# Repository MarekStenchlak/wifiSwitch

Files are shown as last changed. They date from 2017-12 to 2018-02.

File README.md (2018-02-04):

# wifiSwitch

## MQTT wifi wall switch using ESP8266-01

### Description
Switch can be controlled via **MQTT** or **touch button.**

it is well suited for 68mm Europe wall boxes.

Switch is based on wifi board [ESP8266-01](https://en.wikipedia.org/wiki/ESP8266).

Code is implemented in Arduino. Source files can be found in repository.

**This project requires 220V mains to operate properly**

**If you are not familiar with mains DO NOT TRY TO INSTALL THIS SWITCH**

**Proceed only if you know what you are doing !!!**

Board can be ordered on OSH park:
  https://oshpark.com/shared_projects/9JxnbNwu

### Schematics
Schematics for this project was designed using Eagle.

Eagle project can be found in repository.

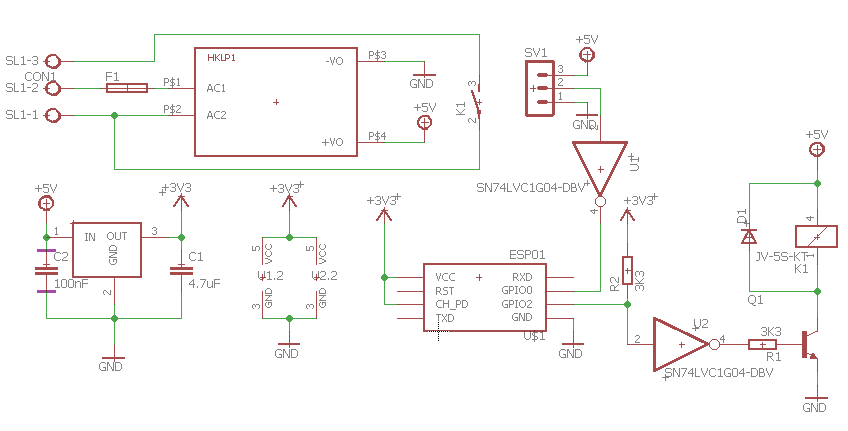
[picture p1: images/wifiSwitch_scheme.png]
Eagle Scheme Schematics


### Board

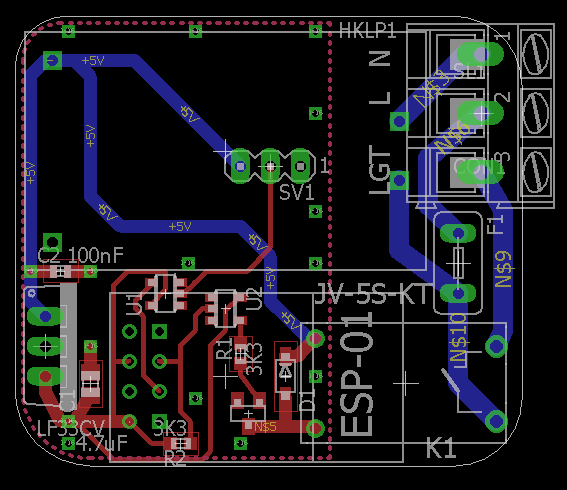
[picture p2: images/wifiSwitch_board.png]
Eagle Board Board


### BOM (Bill Of Materials)
*TODO*

### 3D model
3D model was designed in Sketch-Up and exported to STL files.

Model consists of 3 parts: **box, frame and button cover.**

3D model files and exported STL files can be found in repository.

Exploded view looks like this:

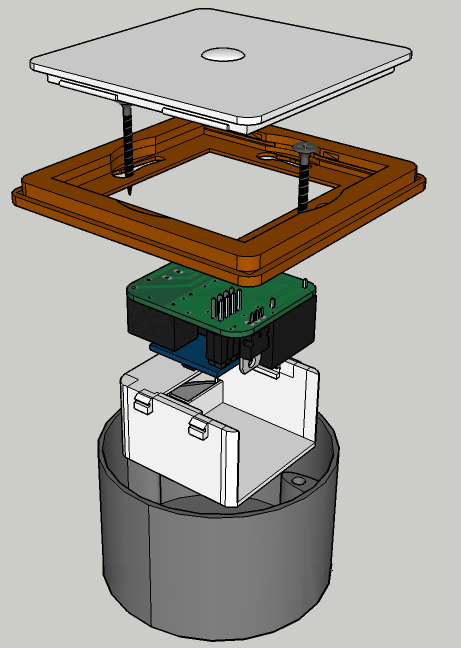
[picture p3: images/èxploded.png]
3D exploded view 3D exploded


## Setup

### Wiring
**Be sure you know what you are doing! Never touch any live wires ! Be sure to turn off electricity when dealing with mains!**

If you do not have **Neutral** wire in the wall box (which you probably don`t), you will have to wire new cable and connect it to **Neutral.**

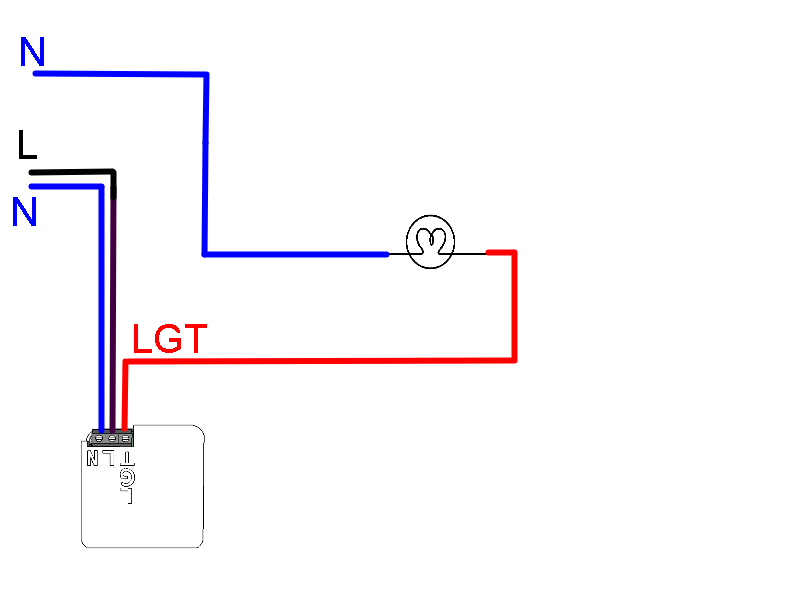
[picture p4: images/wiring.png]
wiring diagram


### MQTT broker
To use this switch you need to have an MQTT broker like [Mosquitto](https://mosquitto.org/) installed on a server or RaspeberryPi in your local wifi network.

To install Mosquitto, please follow this guide: [Setup mosquitto MQTT broker](https://www.digitalocean.com/community/tutorials/how-to-install-and-secure-the-mosquitto-mqtt-messaging-broker-on-ubuntu-16-04)

or this guie for RaspberryPi: [Setup mosquitto MQTT broker on RPi](http://www.instructables.com/id/Installing-MQTT-BrokerMosquitto-on-Raspberry-Pi/)

The bast practise is to set static IP address to the MQTT broker server or raspberryPi running mosquitto.

### WifiSwitch settings
This switch is using [WifiManager](https://github.com/tzapu/WiFiManager) project to set-up switch parameters.

When the switch is connected to mains, it tries to connect to configured Wifi network and MQTT broker. If it is not able to connect or is not configured, it enters the configuration mode.

#### Configuration mode
  When in configuration mode, the switch creates its own wifi network.
  This network`s SSID consists of string "ESP_HOME" followed by its MAC address 
  
  e.g: ESP_HOME A1:B2:3A:4E:2D:E2
    
  This network has no Password.
  
  After you connect to this network (e.g using smartphone) enter IP address 
  
  **192.168.4.1**
  
  Then configure:
  
  wifi SSID
  
  wifi Password
  
  MQTT broker IP (or DNS name)
  
  MQTT broker port
  
  MQTT username
  
  MQTT password
  
  MQTT topic
    
## Final Product

### Assembled board
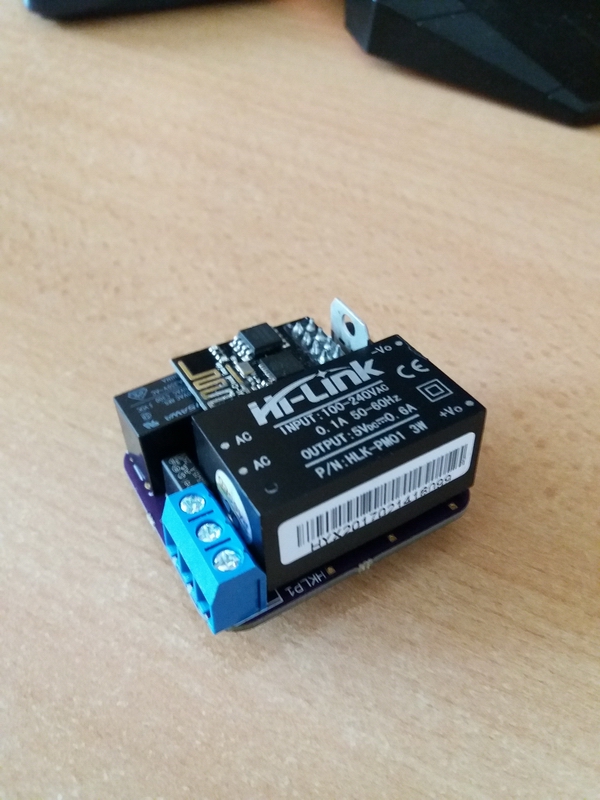
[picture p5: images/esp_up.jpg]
Assembled board 1 Assembled Board1


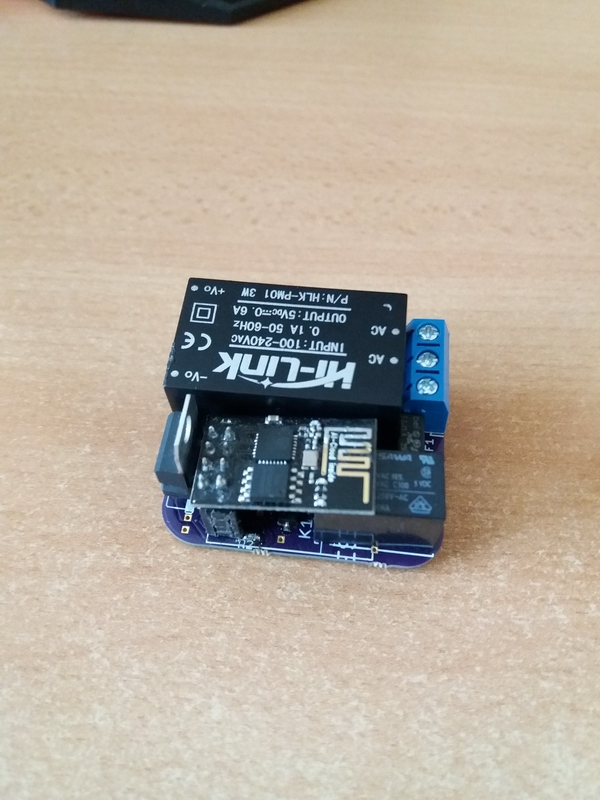
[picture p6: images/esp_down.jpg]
Assembled board 2 Assembled Board2


### Assembled switch

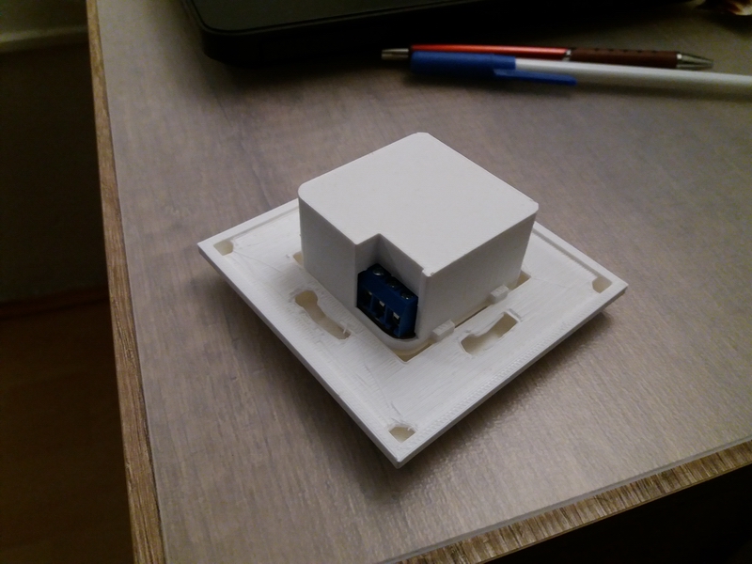
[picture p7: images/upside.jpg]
Assembled switch 1


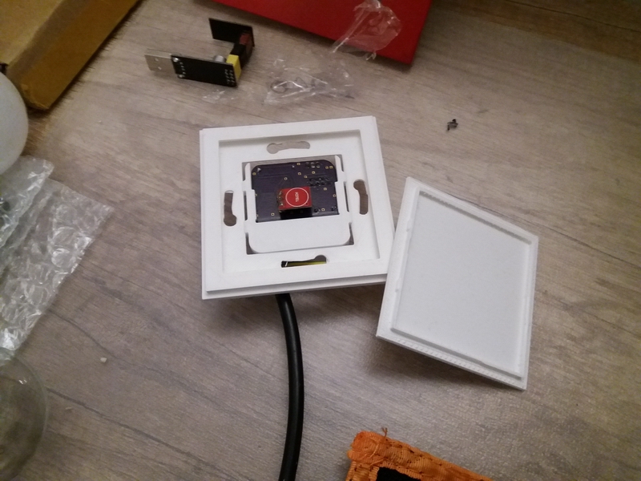
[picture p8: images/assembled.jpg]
Assembled switch 2


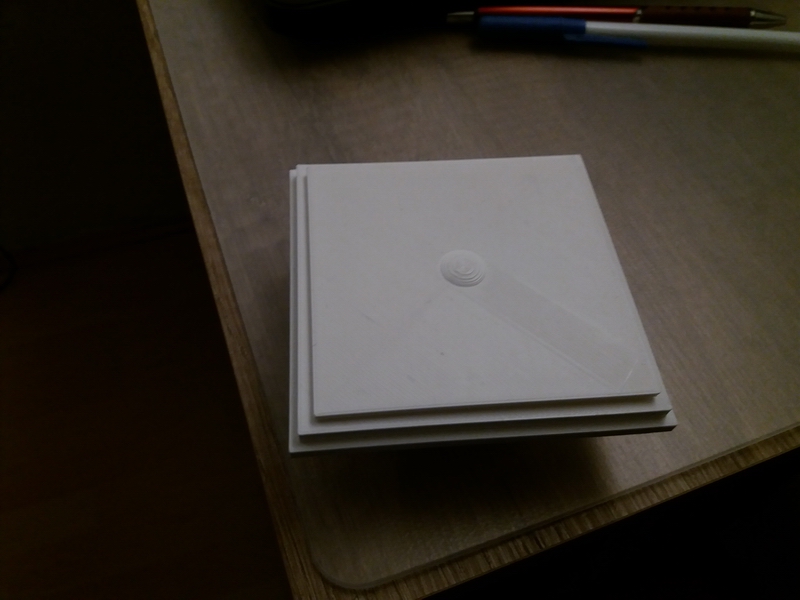
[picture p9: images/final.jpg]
Assembled switch 3


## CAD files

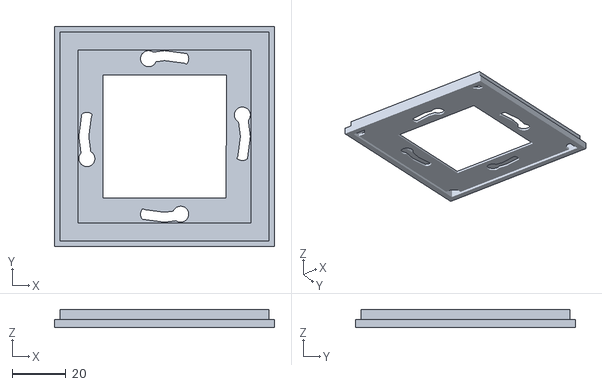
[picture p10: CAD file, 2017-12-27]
3d model/stl/frame.stl
81.7 x 81.7 x 6.77

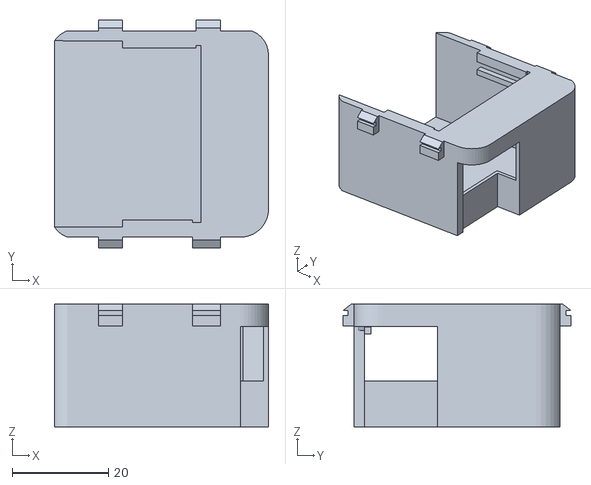
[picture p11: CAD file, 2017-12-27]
3d model/stl/box_rounded.stl
44.5 x 47.3 x 25.5

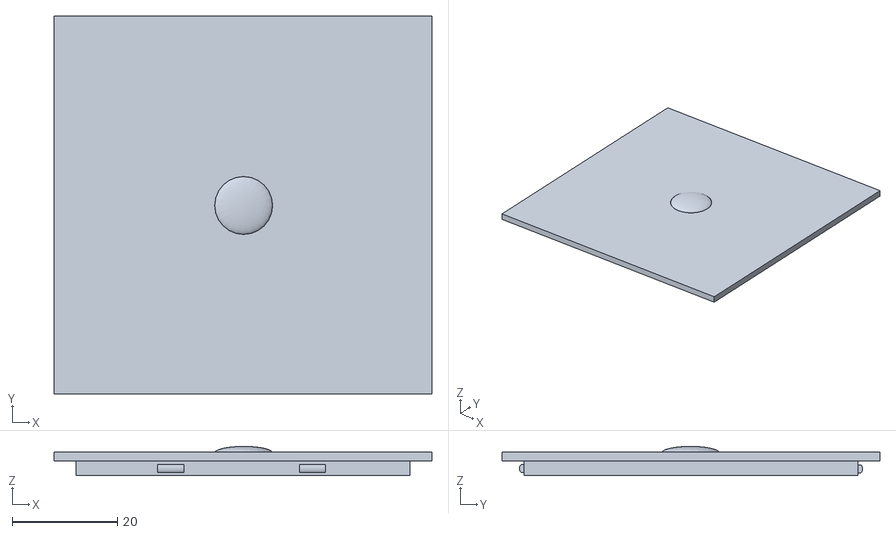
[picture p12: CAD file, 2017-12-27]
3d model/stl/button_flat.stl
71.7 x 71.7 x 5.55

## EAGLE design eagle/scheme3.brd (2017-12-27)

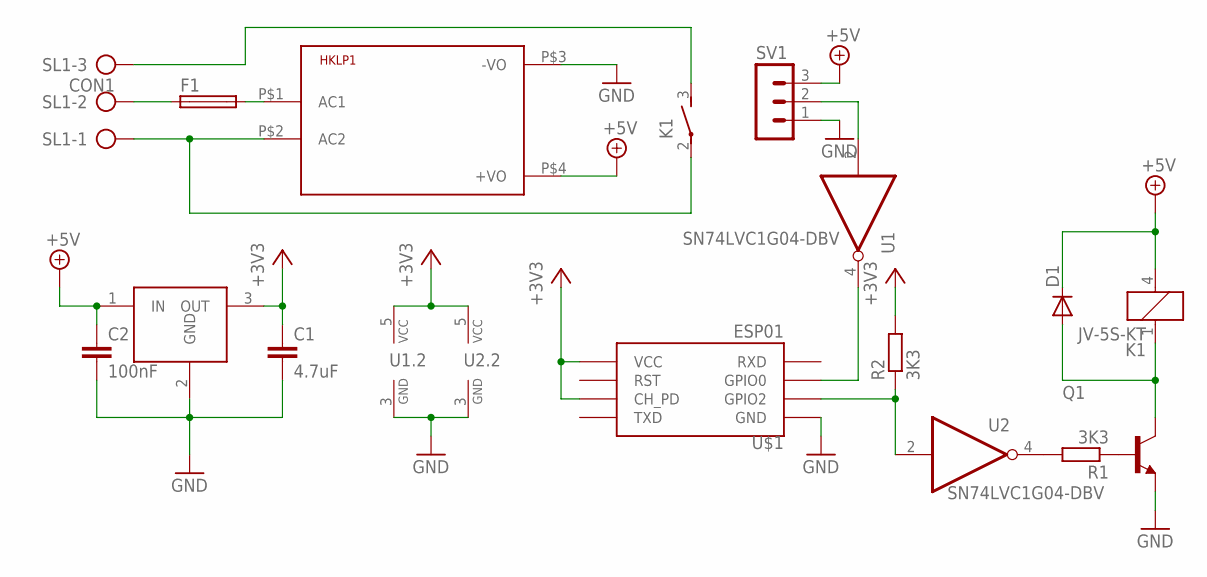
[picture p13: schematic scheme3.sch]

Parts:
C1: 4.7uF; C0805
C2: 100nF; C0603
D1: D-SOD123; SOD123
F1: TE5
HKLP1: HKLPM01
K1: JV-5S-KT; JV-KT
Q1: BC817-16-NPN-SOT23-BEC; SOT23-BEC
R1, R2: 3K3; R0603
SL1: CON1; AK300/3
SV1: MA03-1
U1, U2: SN74LVC1G04-DBV; SOT23-5
U$1: ESP01
U$2: LF33CV; TO220V

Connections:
+3V3: C1.1, R2.2, U1.5 (VCC), U2.5 (VCC), U$1.CH_PD, U$1.VCC, U$2.3 (OUT)
+5V: C2.1, D1.1 (C), HKLP1.P$4 (+VO), K1.4 (2), SV1.3, U$2.1 (IN)
GND: C1.2, C2.2, HKLP1.P$3 (-VO), Q1.E, SV1.1, U1.3 (GND), U2.3 (GND), U$1.GND, U$2.2 (GND)
unnamed: Q1.B, R1.1
unnamed: R2.1, U2.2 (A), U$1.GPIO2
unnamed: R1.2, U2.4 (Y)
unnamed: D1.2 (A), K1.1, Q1.C
unnamed: F1.1, SL1.2
unnamed: SV1.2, U1.2 (A)
unnamed: HKLP1.P$2 (AC2), K1.2, SL1.1
unnamed: K1.3 (S), SL1.3
unnamed: F1.2, HKLP1.P$1 (AC1)
unnamed: U1.4 (Y), U$1.GPIO0

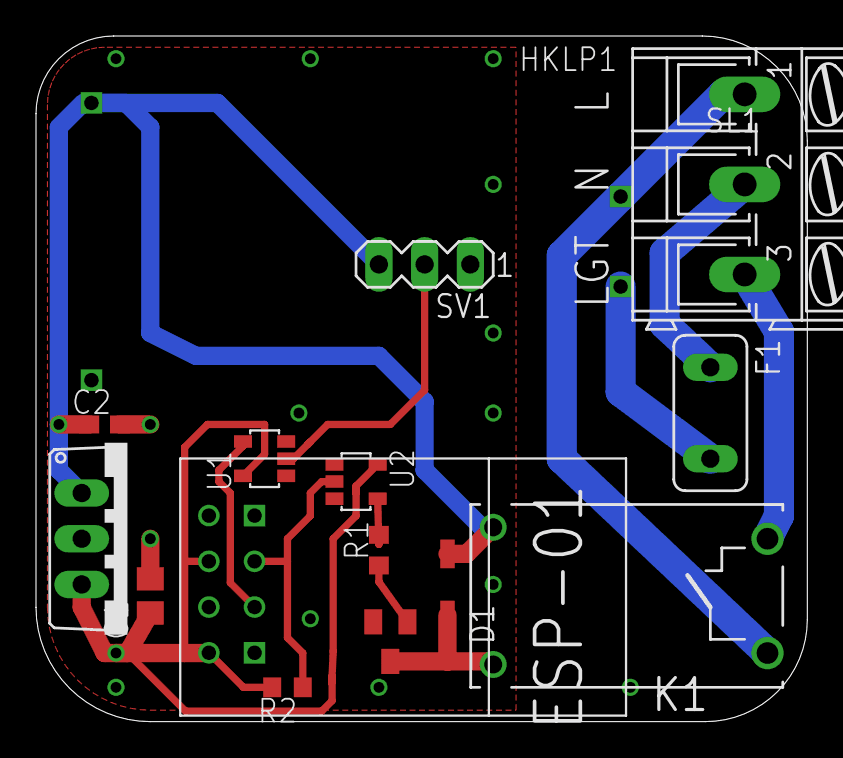
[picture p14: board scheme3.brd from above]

Board: 2 copper layers, 42.9 x 38.1 mm, 15 parts (0 on the bottom side), 13 nets.

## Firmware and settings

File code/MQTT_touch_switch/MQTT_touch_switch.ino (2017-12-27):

#include <FS.h>                   //this needs to be first, or it all crashes and burns...

#include <ESP8266WiFi.h>          //https://github.com/esp8266/Arduino
#include <DNSServer.h>
#include <ESP8266WebServer.h>
#include <WiFiManager.h>          //https://github.com/tzapu/WiFiManager
#include <ArduinoJson.h>          //https://github.com/bblanchon/ArduinoJson
#include <PubSubClient.h>         //https://github.com/knolleary/pubsubclient
#include "OneButton.h"            //https://github.com/mathertel/OneButton

#define BUTTON_PIN       0
#define RELAY_PIN       2
#define DISCOVERY_TOPIC "discovery"
#define STATE_SUFFIX "/state"
#define LONG_PRESS_RESET_VALUE 5 // time to reset ESP8266 to Configuration state in seconds

//flag for saving data
bool shouldSaveConfig = false;

//define your default values here, if there are different values in config.json, they are overwritten.
//char mqtt_server[40];
char mqtt_server[50];
char mqtt_port[6];
char mqtt_user[40];
char mqtt_pass[40];
char mqtt_topic[45];

volatile boolean relayStatus = true; // The logic is inverted, switch is opened on "1" .
volatile boolean isPublishStatus = false;

WiFiManager wifiManager;

WiFiClient espClient;
PubSubClient client(espClient);

OneButton button(BUTTON_PIN, true);

//callback notifying us of the need to save config
void saveConfigCallback () {
  Serial.println("Should save config");
  shouldSaveConfig = true;
}

// MQTT callback
void callback(char* topic, byte* payload, unsigned int length) {
  
  if (strcmp(topic, mqtt_topic) == 0){
    // Switch ON the relay if "1" was received as the first character on the topic
    if ((char)payload[0] == '1') {
      // inverse logic because of inverter in the circuit
      relayStatus = false;
    }  
    // Switch OFF the relay if "0" was received as the first character on the topic
    if ((char)payload[0] == '0') {
      // inverse logic because of inverter in the circuit
      relayStatus = true;
    }
    // Toggle the relay if "2" was received as the first character on the topic
    if ((char)payload[0] == '2') {
      relayStatus = !relayStatus;
    }
    // MQTT command to reset the ESP
    // Reset the ESP if "x" was received as the first character on the topic
    if ((char)payload[0] == 'x')
    {
      Serial.println("Reseting ESP...");
      //client.disconnect();
      runOnDemandSetup();
    }
    // debug output
    Serial.println(relayStatus);
    
    digitalWrite(RELAY_PIN, relayStatus);
    publishStatus(mqtt_topic);
  }
  
  if (strcmp(topic, DISCOVERY_TOPIC) == 0)
  {
    if ((char)payload[0] == '1') {
      publishStatus(mqtt_topic);
    }
  }
}

void setup() {
  // put your setup code here, to run once:
  //Serial.begin(115200);
  Serial.begin(115200,SERIAL_8N1,SERIAL_TX_ONLY);
  Serial.println();

  pinMode(RELAY_PIN, OUTPUT);
  digitalWrite(RELAY_PIN, relayStatus);

  // set Touch pin to input  > interupt
  pinMode(BUTTON_PIN, INPUT);
  
  button.attachClick(oneClickFunction);
  button.attachLongPressStart(longPressStart);
  button.attachLongPressStop(longPressStop);
  button.attachDuringLongPress(longPress);
  button.setPressTicks(LONG_PRESS_RESET_VALUE*1000);
  //clean FS for testing 
  //SPIFFS.format();

  //read configuration from FS json
  Serial.println("mounting FS...");

  if (SPIFFS.begin()) {
    Serial.println("mounted file system");
    if (SPIFFS.exists("/config.json")) {
      //file exists, reading and loading
      Serial.println("reading config file");
      File configFile = SPIFFS.open("/config.json", "r");
      if (configFile) {
        Serial.println("opened config file");
        size_t size = configFile.size();
        // Allocate a buffer to store contents of the file.
        std::unique_ptr<char[]> buf(new char[size]);

        configFile.readBytes(buf.get(), size);
        DynamicJsonBuffer jsonBuffer;
        JsonObject& json = jsonBuffer.parseObject(buf.get());
        json.printTo(Serial);
        if (json.success()) {
          Serial.println("\nparsed json");
          strcpy(mqtt_server, json["mqtt_server"]);
          strcpy(mqtt_port, json["mqtt_port"]);
          strcpy(mqtt_user, json["mqtt_user"]);
          strcpy(mqtt_pass, json["mqtt_pass"]);
          strcpy(mqtt_topic, json["mqtt_topic"]);
        } else {
          Serial.println("failed to load json config");
        }
      }
    }
  } else {
    Serial.println("failed to mount FS");
  }
  //end read

  // The extra parameters to be configured (can be either global or just in the setup)
  // After connecting, parameter.getValue() will get you the configured value
  // id/name placeholder/prompt default length
  WiFiManagerParameter custom_mqtt_server("server", "mqtt server", mqtt_server, 40);
  WiFiManagerParameter custom_mqtt_port("port", "mqtt port", mqtt_port, 6);
  WiFiManagerParameter custom_mqtt_user("user", "mqtt user", mqtt_user, 20);
  WiFiManagerParameter custom_mqtt_pass("pass", "mqtt pass", mqtt_pass, 20);
  WiFiManagerParameter custom_mqtt_topic("topic", "mqtt topic", mqtt_topic, 25);

  //WiFiManager
  //Local intialization. Once its business is done, there is no need to keep it around

  //set config save notify callback
  wifiManager.setSaveConfigCallback(saveConfigCallback);

  //set static ip
//  wifiManager.setSTAStaticIPConfig(IPAddress(10,0,1,99), IPAddress(10,0,1,1), IPAddress(255,255,255,0));
  
  //add all your parameters here
  wifiManager.addParameter(&custom_mqtt_server);
  wifiManager.addParameter(&custom_mqtt_port);
  wifiManager.addParameter(&custom_mqtt_user);
  wifiManager.addParameter(&custom_mqtt_pass);
  wifiManager.addParameter(&custom_mqtt_topic);

  //reset settings - for testing
  //wifiManager.resetSettings();

  //set minimum quality of signal so it ignores AP's under that quality
  //defaults to 8%
  //wifiManager.setMinimumSignalQuality();
  
  //sets timeout until configuration portal gets turned off
  //useful to make it all retry or go to sleep
  //in seconds
  wifiManager.setTimeout(180);

  //fetches ssid and pass and tries to connect
  //if it does not connect it starts an access point with the specified name
  //here  "AutoConnectAP"
  //and goes into a blocking loop awaiting configuration

  String wifiName = "ESP_HOME ";
  uint8_t mac[6];
  WiFi.macAddress(mac);
  wifiName += macToStr(mac);

  char WN[40];
  wifiName.toCharArray(WN, 40);
  
  if (!wifiManager.autoConnect(WN)) {
    Serial.println("failed to connect and hit timeout");
    delay(3000);
    //reset and try again, or maybe put it to deep sleep
    
   // wifiManager.resetSettings();
    ESP.restart();
    delay(5000);
  }

  //if you get here you have connected to the WiFi
  Serial.println("connected...yeey :)");

  //read updated parameters
  strcpy(mqtt_server, custom_mqtt_server.getValue());
  strcpy(mqtt_port, custom_mqtt_port.getValue());
  strcpy(mqtt_user, custom_mqtt_user.getValue());
  strcpy(mqtt_pass, custom_mqtt_pass.getValue());
  strcpy(mqtt_topic, custom_mqtt_topic.getValue());
 

  //save the custom parameters to FS
  if (shouldSaveConfig) {
    Serial.println("saving config");
    DynamicJsonBuffer jsonBuffer;
    JsonObject& json = jsonBuffer.createObject();
    json["mqtt_server"] = mqtt_server;
    json["mqtt_port"] = mqtt_port;
    json["mqtt_user"] = mqtt_user;
    json["mqtt_pass"] = mqtt_pass;
    json["mqtt_topic"] = mqtt_topic;

    File configFile = SPIFFS.open("/config.json", "w");
    if (!configFile) {
      Serial.println("failed to open config file for writing");
    }

    json.printTo(Serial);
    json.printTo(configFile);
    configFile.close();
    //end save
  }

  Serial.println("local ip");
  Serial.println(WiFi.localIP());

  client.setServer(mqtt_server, atoi(mqtt_port));
  client.setCallback(callback);
}

void publishStatus(char* topicToPublish)
{
  char buf[40];
  char payload[4];
  strcpy(buf,topicToPublish);
  strcat(buf,STATE_SUFFIX);
  if(relayStatus == true)
    strcpy(payload,"0");
  else
    strcpy(payload,"1");
  client.publish(buf, payload);
}

String macToStr(const uint8_t* mac)
{
  String result;
  for (int i = 0; i < 6; ++i) {
    result += String(mac[i], 16);
    if (i < 5)
      result += ':';
  }
  return result;
}

void reconnect() {
  // Loop until we're reconnected
  while (!client.connected()) {
    //digitalWrite(RELAY_PIN, false);
    Serial.print("Attempting MQTT connection...");
    
    // Attempt to connect
    // If you do not want to use a username and password, change next line to
    // if (client.connect("ESP8266Client")) {
    //set client id
  // Generate client name based on MAC address and last 8 bits of microsecond counter
  String clientName;
  uint8_t mac[6];
  button.tick();
  WiFi.macAddress(mac);
  clientName += macToStr(mac);
  clientName += "-";
  clientName += String(micros() & 0xff, 16);
  char id[35];
  clientName.toCharArray(id, 35);
    if (client.connect(id, mqtt_user, mqtt_pass)) {
      Serial.println("connected");
      client.subscribe(mqtt_topic);
      client.subscribe(DISCOVERY_TOPIC);
      Serial.print("Subscribed to topics: ");
      Serial.println(mqtt_topic);
      Serial.println(DISCOVERY_TOPIC);
      publishStatus(mqtt_topic);
    } else {
      Serial.print("failed, rc=");
      Serial.print(client.state());
      Serial.println(" try again in 5 seconds");
      // Wait 5 seconds before retrying
      delay(5000);
    }
  }
}

void runOnDemandSetup()
{
  if (client.connected())
  {
    client.disconnect();
  }
  SPIFFS.format();
  wifiManager.resetSettings();
  ESP.restart();
  //setup();
}

// Button handling 
void oneClickFunction() {
  // callback for button click, sets the flag to toggle switch
  isPublishStatus = true;
}

void longPressStart() {
  relayStatus = !relayStatus;
  publishStatus(mqtt_topic);
  runOnDemandSetup();
} // longPressStart

void longPress() {
  
} // longPress

void longPressStop() {
    
} // longPressStop

// main loop
void loop() {
  // put your main code here, to run repeatedly:
  
  if (!client.connected()) {
    reconnect();
  }
  // if flag from button click is set to true
  if (isPublishStatus)
  {
    relayStatus = !relayStatus;
    digitalWrite(RELAY_PIN, relayStatus);
    publishStatus(mqtt_topic);
    Serial.println("Change from button !");  
    isPublishStatus = false;
  }
  button.tick();
  client.loop();
}

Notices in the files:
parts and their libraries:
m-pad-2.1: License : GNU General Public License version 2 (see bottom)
